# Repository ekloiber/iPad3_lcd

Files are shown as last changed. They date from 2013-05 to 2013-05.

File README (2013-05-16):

Originally:

Schematics of an interface board for connecting an iPad retina display (LP097QX1-SPA1) to a DisplayPort source.

Revised:

PCB for connecting an iPad 3 LCD screen to displayport and using an inexpensive capacitive touch screen digitizer as a USB multi-touch device.

Goals:
- Inexpensive (~$100)
- Accessible for modification
- Open source
- Simple construction 
  - PCB through OSH Park
  - Case through laser-cut acrylic
  - Parts throuh suppliers like AliExpress, Mouser

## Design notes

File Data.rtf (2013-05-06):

⁃ iPad LCD

Total area
208.881mm x 167.123mm
8.22in x 6.58in
View area
196.608mm x 147.456mm
7.74in x 5.81in

9.7" Capacitive Digitizer (Flytouch 3 G08S PB97DR971)

Total area
237mm x 180mm
9.33in x 7.09in
View area
198mm x 164mm
7.80in x 6.46in

Connector
6pin FPC - 3.5mm width, 0.5mm pitch (eg Molex 501461-0601)
Top-down:
1. RESET
2. SDA
3. SCl
4. INT
5. VDD
6. GND

IC: FT5406EE8
http://www.displayfuture.com/Display/datasheet/controller/FT5x06.pdf
http://www.newhavendisplay.com/app_notes/FT5x06.pdf

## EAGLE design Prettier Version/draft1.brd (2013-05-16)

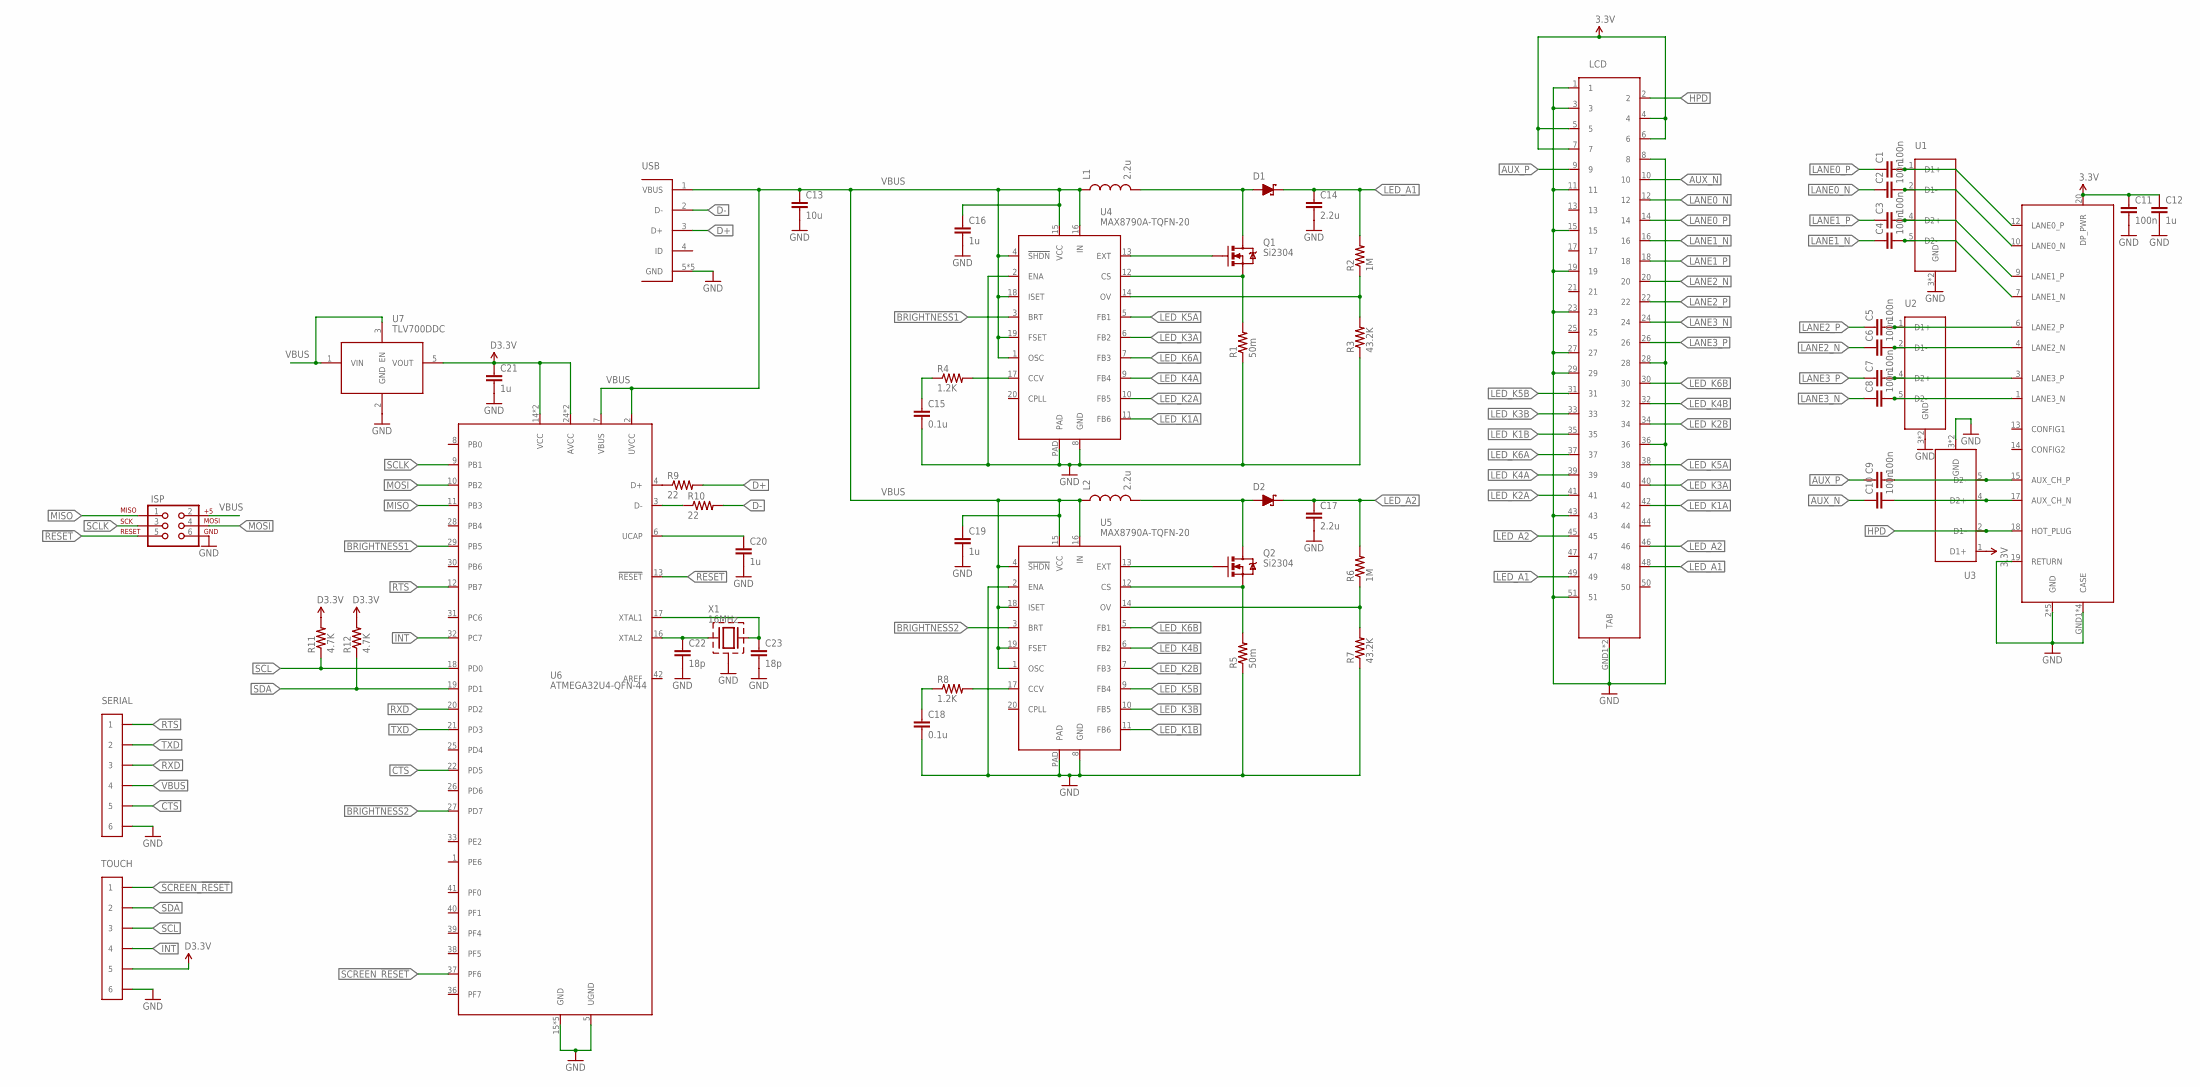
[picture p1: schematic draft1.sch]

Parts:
C1, C2, C3, C4, C5, C6, C7, C8, C9, C10: 100n; C0402
C11: 100n; C0805
C12: 1u; C0805
C13: 10u; C1206
C14, C17: 2.2u; C1206
C15, C18: 0.1u; C0603
C16, C19, C20, C21: 1u; C0603
C22, C23: 18p; C0603
D1, D2: DB2W40300L; MINI2-F3-B
DP: DISPLAYPORT-SINK-MOLEX; MOLEX-47272-0028
ISP: AVR_SPI_PRG_6PTH; 2X3
L1, L2: 2.2u; 1210
LCD: CONN-51P-FPC-MOLEX; MOLEX-502250-5191
Q1, Q2: Si2304; SOT23-3
R1, R5: 50m; MCS1632
R2, R6: 1M; R0603
R3, R7: 43.2K; R0603
R4, R8: 1.2K; R0603
R9, R10: 22; R0603
R11, R12: 4.7K; R0603
SERIAL: HEADER-6X1-961106-5500; HEADER-3M-961-6P-2.54MM
TOUCH: HEADER-6X1-FPC-DUAL_CONTACT; MOLEX-503480-0600
U1, U2, U3: ESD-SUPPRESSOR-4-TPD4S010-DQA; SON-10
U4, U5: MAX8790A-TQFN-20; TQFN-20
U6: ATMEGA32U4-QFN-44; QFN-44
U7: TLV700DDC; SOT-23-5
USB: USB_MICRO_AB
X1: 16MHz; ABM3C

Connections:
3.3V: C11.1, C12.1, DP.20 (DP_PWR), LCD.4, LCD.5, LCD.6, LCD.7, U3.1 (D1+)
!RESET: ISP.5, U6.13 (!RESET)
AUX_N: C10.1, LCD.10
AUX_P: C9.1, LCD.9
BRIGHTNESS1: U4.3 (BRT), U6.29 (PB5)
BRIGHTNESS2: U5.3 (BRT), U6.27 (PD7)
CTS: SERIAL.5, U6.22 (PD5)
D3.3V: C21.1, R11.2, R12.2, TOUCH.5, U6.14 (VCC), U6.24 (AVCC), U6.34 (VCC), U6.44 (AVCC), U7.5 (VOUT)
D+: R9.2, USB.3 (D+)
D-: R10.2, USB.2 (D-)
GND: C11.2, C12.2, C13.2, C14.2, C15.2, C16.2, C17.2, C18.2, C19.2, C20.2, C21.2, C22.2, C23.2, DP.2 (GND), DP.5 (GND), DP.8 (GND), DP.11 (GND), DP.16 (GND), DP.19 (RETURN), DP.GND1 (CASE), DP.GND2 (CASE), DP.GND3 (CASE), DP.GND4 (CASE), ISP.6, LCD.1, LCD.3, LCD.8, LCD.11, LCD.15, LCD.19, LCD.23, LCD.27, LCD.28, LCD.29, LCD.36, LCD.43, LCD.51, LCD.GND1 (TAB), LCD.GND2 (TAB), R1.1, R3.1, R5.1, R7.1, SERIAL.6, TOUCH.6, U1.3 (GND), U1.8 (GND), U2.3 (GND), U2.8 (GND), U3.3 (GND), U3.8 (GND), U4.2 (ENA), U4.8 (GND), U4.PAD, U5.2 (ENA), U5.8 (GND), U5.PAD, U6.5 (UGND), U6.15 (GND), U6.23 (GND), U6.35 (GND), U6.43 (GND), U6.PAD (GND), U7.2 (GND), USB.5 (GND), USB.GND1 (GND), USB.GND2 (GND), USB.GND3 (GND), USB.GND4 (GND), X1.2 (CASE), X1.4 (CASE)
HPD: DP.18 (HOT_PLUG), LCD.2, U3.2 (D1-)
INT: TOUCH.4, U6.32 (PC7)
LANE0_N: C2.1, LCD.12
LANE0_P: C1.1, LCD.14
LANE1_N: C4.1, LCD.16
LANE1_P: C3.1, LCD.18
LANE2_N: C6.1, LCD.20
LANE2_P: C5.1, LCD.22
LANE3_N: C8.1, LCD.24
LANE3_P: C7.1, LCD.26
LED_A1: C14.1, D1.1 (K), LCD.48, LCD.49, R2.2
LED_A2: C17.1, D2.1 (K), LCD.45, LCD.46, R6.2
LED_K1A: LCD.42, U4.11 (FB6)
LED_K1B: LCD.35, U5.11 (FB6)
LED_K2A: LCD.41, U4.10 (FB5)
LED_K2B: LCD.34, U5.7 (FB3)
LED_K3A: LCD.40, U4.6 (FB2)
LED_K3B: LCD.33, U5.10 (FB5)
LED_K4A: LCD.39, U4.9 (FB4)
LED_K4B: LCD.32, U5.6 (FB2)
LED_K5A: LCD.38, U4.5 (FB1)
LED_K5B: LCD.31, U5.9 (FB4)
LED_K6A: LCD.37, U4.7 (FB3)
LED_K6B: LCD.30, U5.5 (FB1)
MISO: ISP.1, U6.11 (PB3)
MOSI: ISP.4, U6.10 (PB2)
unnamed: C4.2, DP.7 (LANE1_N), U1.5 (D2-)
unnamed: C3.2, DP.9 (LANE1_P), U1.4 (D2+)
unnamed: C2.2, DP.10 (LANE0_N), U1.2 (D1-)
unnamed: C1.2, DP.12 (LANE0_P), U1.1 (D1+)
unnamed: C5.2, DP.6 (LANE2_P), U2.1 (D1+)
unnamed: C6.2, DP.4 (LANE2_N), U2.2 (D1-)
unnamed: C7.2, DP.3 (LANE3_P), U2.4 (D2+)
unnamed: C8.2, DP.1 (LANE3_N), U2.5 (D2-)
unnamed: C9.2, DP.15 (AUX_CH_P), U3.5 (D2-)
unnamed: C10.2, DP.17 (AUX_CH_N), U3.4 (D2+)
unnamed: Q1.2 (S), R1.2, U4.12 (CS)
unnamed: Q2.1 (G), U5.13 (EXT)
unnamed: Q1.1 (G), U4.13 (EXT)
unnamed: D1.2 (A), L1.2, Q1.3 (D)
unnamed: R2.1, R3.2, U4.14 (OV)
unnamed: R4.2, U4.17 (CCV)
unnamed: C15.1, R4.1
unnamed: D2.2 (A), L2.2, Q2.3 (D)
unnamed: Q2.2 (S), R5.2, U5.12 (CS)
unnamed: R6.1, R7.2, U5.14 (OV)
unnamed: R8.2, U5.17 (CCV)
unnamed: C18.1, R8.1
unnamed: R9.1, U6.4 (D+)
unnamed: R10.1, U6.3 (D-)
unnamed: C20.1, U6.6 (UCAP)
unnamed: C22.1, U6.16 (XTAL2), X1.1
unnamed: C23.1, U6.17 (XTAL1), X1.3 (2)
RTS: SERIAL.1, U6.12 (PB7)
RXD: SERIAL.3, U6.20 (PD2)
SCL: R11.1, TOUCH.3, U6.18 (PD0)
SCLK: ISP.3, U6.9 (PB1)
SCREEN_!RESET: TOUCH.1, U6.37 (PF6)
SDA: R12.1, TOUCH.2, U6.19 (PD1)
TXD: SERIAL.2, U6.21 (PD3)
VBUS: C13.1, C16.1, C19.1, ISP.2, L1.1, L2.1, SERIAL.4, U4.1 (OSC), U4.4 (!SHDN), U4.15 (VCC), U4.16 (IN), U4.18 (ISET), U4.19 (FSET), U5.1 (OSC), U5.4 (!SHDN), U5.15 (VCC), U5.16 (IN), U5.18 (ISET), U5.19 (FSET), U6.2 (UVCC), U6.7 (VBUS), U7.1 (VIN), U7.3 (EN), USB.1 (VBUS)

Board: 4 copper layers, 55 parts (0 on the bottom side), 72 nets, no tracks yet.

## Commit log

2013-04-30 Schematic work
    Added LED control
    [draft1.brd, draft1.sch]
2013-05-06 Prelim. PCB layout
    [draft1.brd, draft1.sch]
2013-05-16 Misc updates
    [draft1.brd, draft1.sch]
2013-05-16 Deleted PCB layout
    Pending physical measurements
    [draft1.brd, draft1.sch]

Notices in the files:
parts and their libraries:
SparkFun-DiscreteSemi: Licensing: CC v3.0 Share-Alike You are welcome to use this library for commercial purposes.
